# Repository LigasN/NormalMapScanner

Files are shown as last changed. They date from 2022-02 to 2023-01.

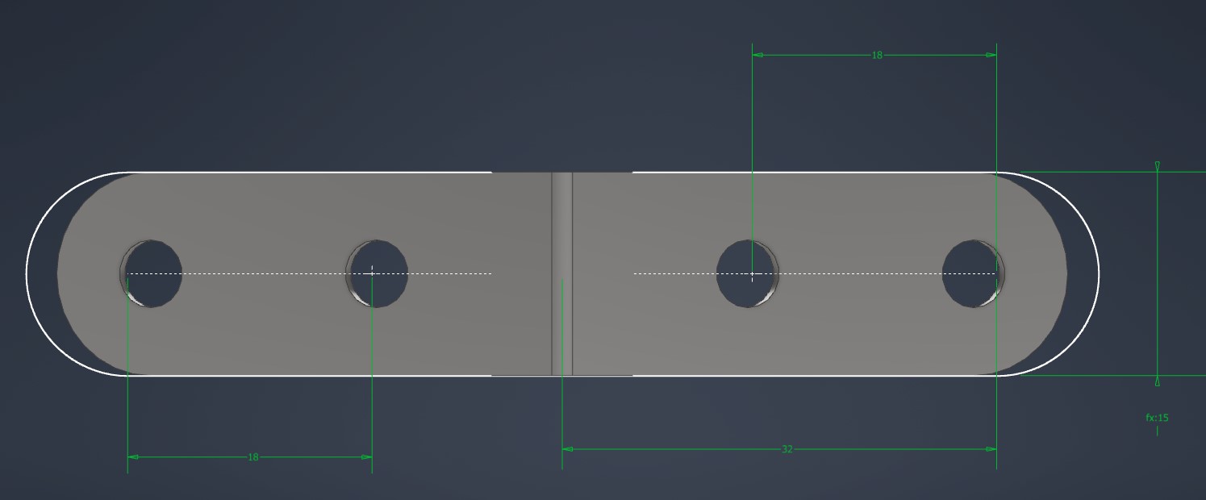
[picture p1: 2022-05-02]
3D_modeling/construction/images/parts/angle_iron_annotations.jpg

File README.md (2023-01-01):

NormalMapScanner https://www.youtube.com/watch?v=KlRckV2yOt0 (https://www.youtube.com/watch?v=KlRckV2yOt0)
# NormalMapScanner
Experimental stand for generating normal maps for quasi-flat objects.

## Description
A fully automatic system that generates normal maps for nearly flat objects. The process of generation consists in taking pictures with spotlighting from different sides and computation of normals. The repository consists of all projects (hardware and software) that combined result in a working stand.

## Discussions
I would like to kindly invite you to check the [discussions page](https://github.com/LigasN/NormalMapScanner/discussions).

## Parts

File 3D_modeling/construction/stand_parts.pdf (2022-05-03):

Name | Image | Amount | Placement Description | Dimensions | Images with annotations
bar_185mm | 8 | leg | Bar placed in the
| | | stand's leg to make possible
| | | changing leg heigth and by that
| | | light source heigth as well, as it is placed on the top part of the leg.
diameter [mm] | 8
heigth [mm] | 185
bar_285mm | 8 | arm | Bar placed in the stand's arm to make possible
| | | changing arm length and by that camera position (heigth) as well.
diameter [mm] | 8
heigth [mm] | 285
bar_connector | 16 | connector | Bar used in the connector's assembly to make possible its width

change. On one
side bar has holes
for screws to attach it to the leg. Lenght was

calculated on the premise that minimum distance between light and

stand center will be 400mm. Then

calculations were:
(
light_to_center_di
stance * sin(alfa) )
/ cos(alfa / 2), where alfa was

the difference between angles of direction of the

consecutives light
sources. Two legs and the stand

center make
triangle with this angle from the

center side.

diameter [mm] | 8
length [mm] | 271

first hole distance
to the edge [mm]

7,5

second hole distance to the edge [mm]

25,5

cut length [mm] | 35
pipe_200mm | 8 | leg | Leg's pipe. One of the holes is to hold bar on certain position and

second to connect with barrel hinge.

length [mm] | 200

inner diameter
[mm]

10

thickness [mm] | 1

upper hole distance to the edge [mm]

8

lower hole distance
to the edge [mm]

10

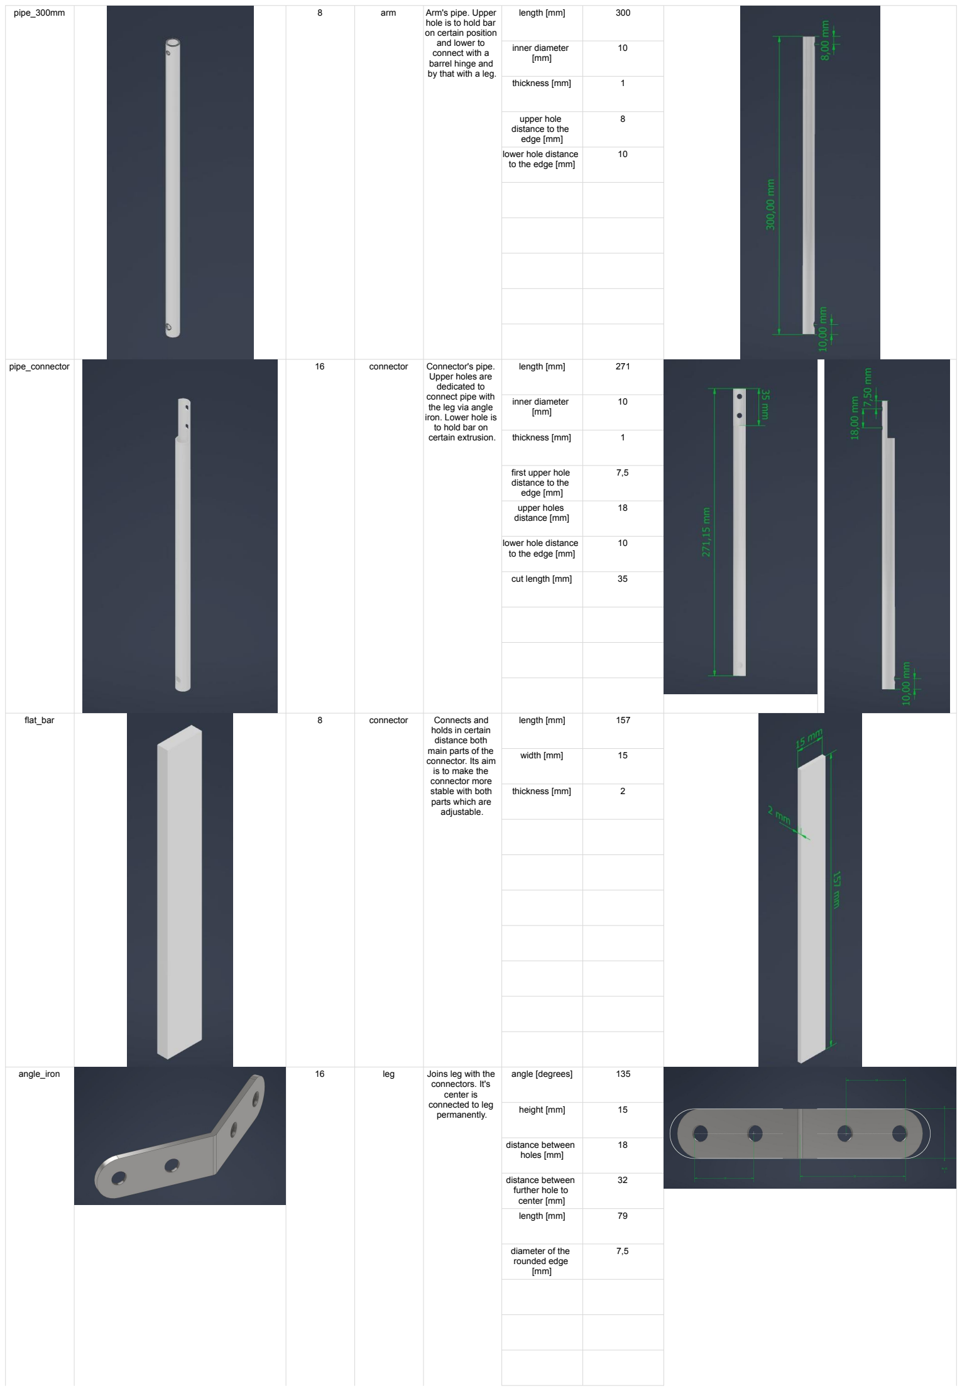
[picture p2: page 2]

pipe_300mm | 8 | arm | Arm's pipe. Upper hole is to hold bar on certain position and lower to

connect with a barrel hinge and by that with a leg.

length [mm] | 300

inner diameter
[mm]

10

thickness [mm] | 1

upper hole distance to the edge [mm]

8

lower hole distance
to the edge [mm]

10

pipe_connector | 16 | connector | Connector's pipe. Upper holes are dedicated to

connect pipe with
the leg via angle
iron. Lower hole is
to hold bar on
certain extrusion.
length [mm] | 271

inner diameter
[mm]

10

thickness [mm] | 1

first upper hole distance to the edge [mm]
7,5

upper holes distance [mm]

18

lower hole distance
to the edge [mm]

10

cut length [mm] | 35
flat_bar | 8 | connector | Connects and holds in certain distance both main parts of the

connector. Its aim
is to make the
connector more
stable with both parts which are adjustable.
length [mm] | 157
width [mm] | 15
thickness [mm] | 2
angle_iron | 16 | leg | Joins leg with the connectors. It's center is connected to leg permanently.
angle [degrees] | 135
height [mm] | 15

distance between holes [mm]

18

distance between
further hole to
center [mm]

32

length [mm] | 79

diameter of the
rounded edge
[mm]

7,5

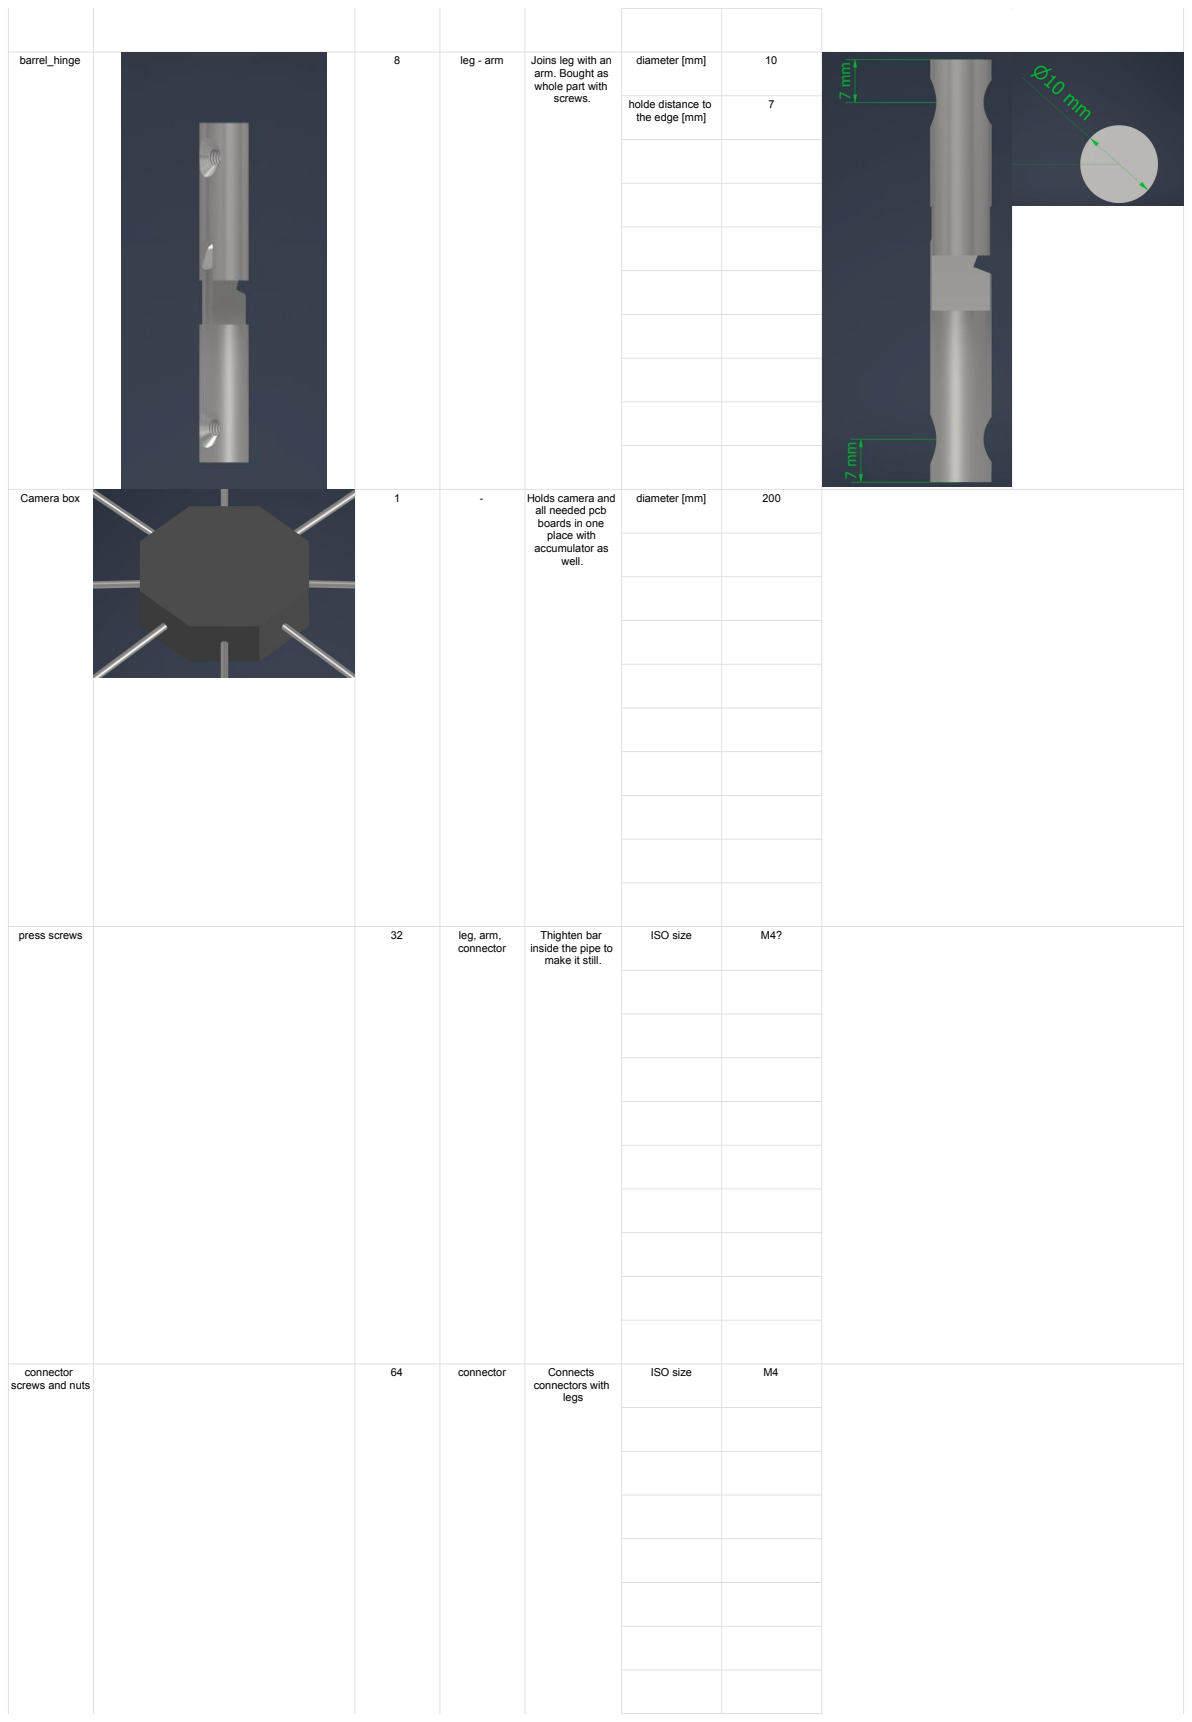
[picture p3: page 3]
barrel_hinge; leg - arm; Joins leg with an arm. Bought as whole part with; screws.; diameter [mm]; Camera box; Holds camera and all needed pcb boards in one place with accumulator as well.; press screws; leg, arm,; connector; ISO size; Connects; connectors with legs

holde distance to
the edge [mm]

Thighten bar
inside the pipe to make it still.

connector
screws and nuts

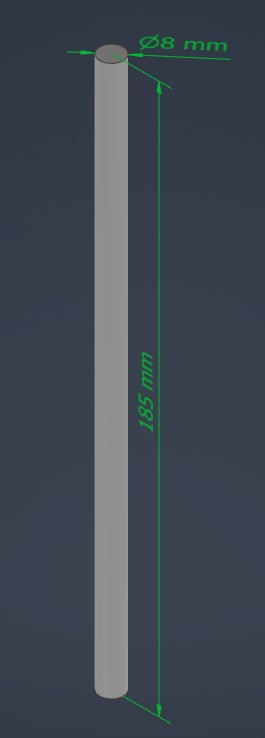
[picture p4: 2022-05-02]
3D_modeling/construction/images/parts/bar_185mm_annotations.jpg

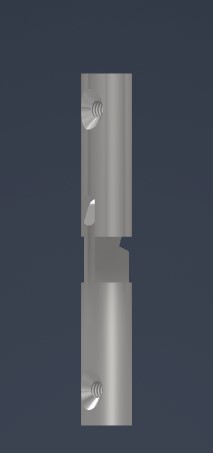
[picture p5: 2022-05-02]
3D_modeling/construction/images/parts/barrel_hinge.jpg

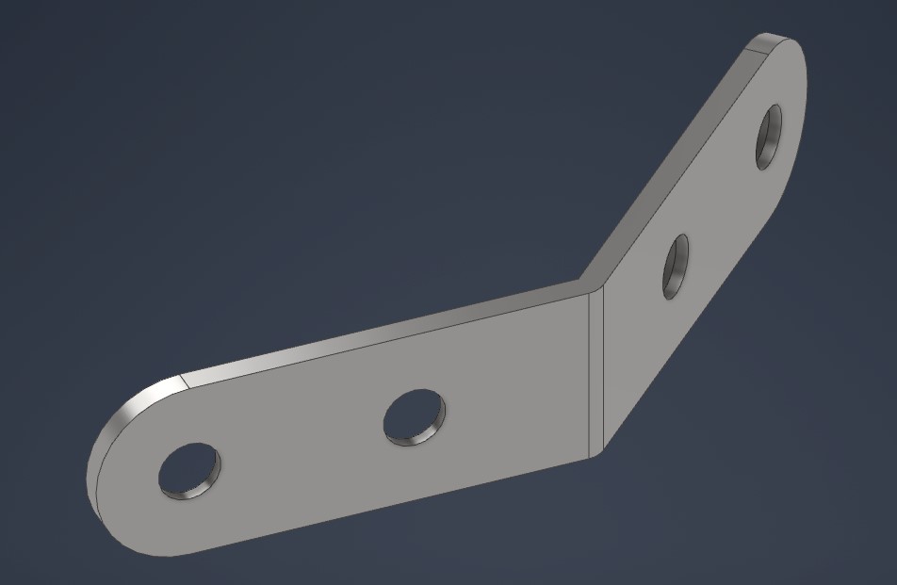
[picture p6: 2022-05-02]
3D_modeling/construction/images/parts/angle_iron.jpg

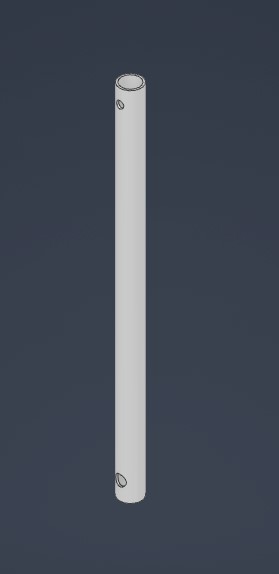
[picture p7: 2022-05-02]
3D_modeling/construction/images/parts/pipe_200mm.jpg

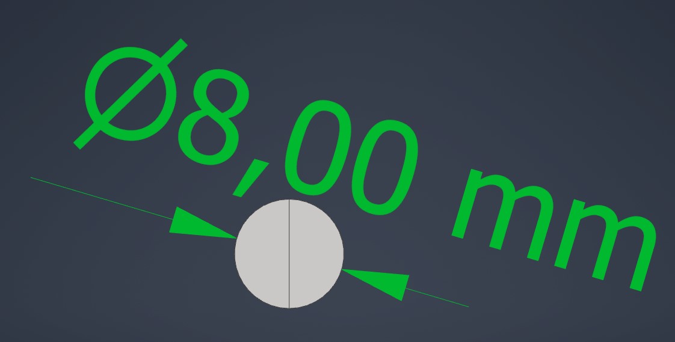
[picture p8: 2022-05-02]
3D_modeling/construction/images/parts/bar_connector_top_annotations.jpg

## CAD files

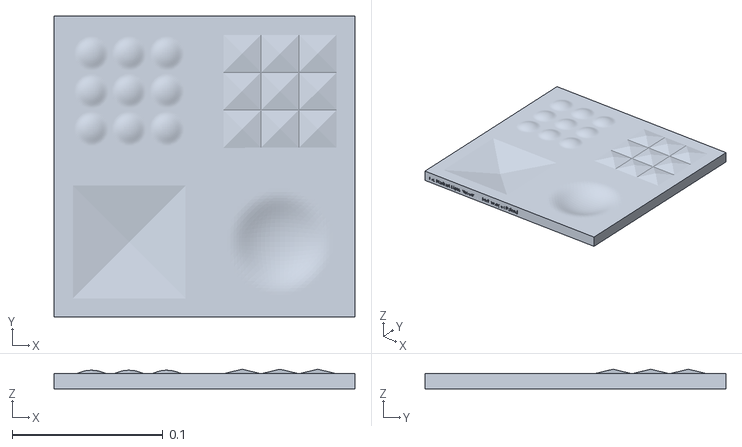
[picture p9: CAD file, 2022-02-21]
3D_modeling/3D_print_models/dice.stl
0.2 x 0.2 x 0.013

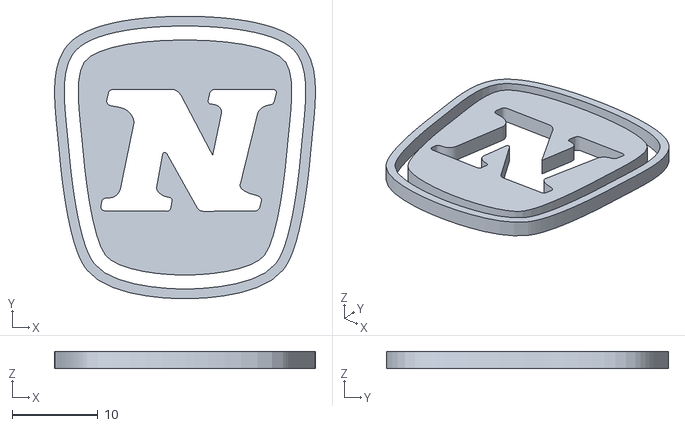
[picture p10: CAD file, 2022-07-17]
3D_modeling/construction/parts/board_box/board_box_cover_assets/n-logo.stl
30.4 x 32.9 x 2.00

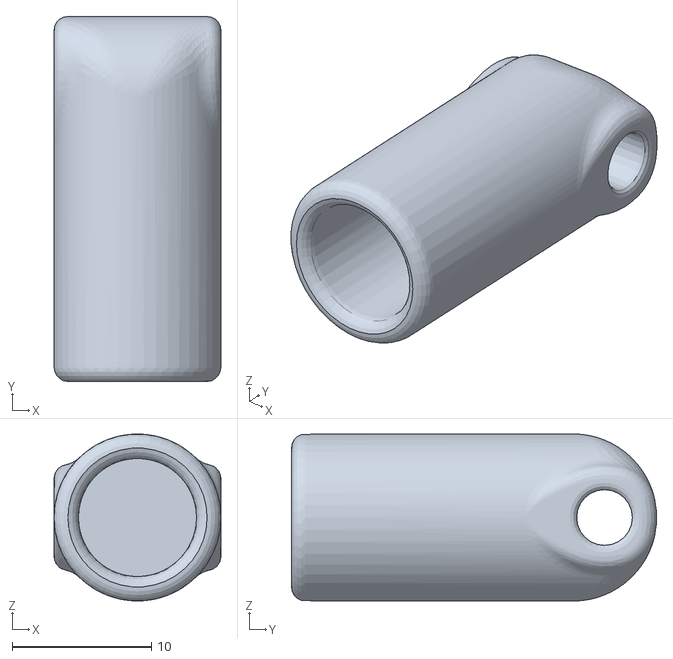
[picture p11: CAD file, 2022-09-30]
3D_modeling/construction/stl/bar_holder.stl
12.0 x 26.2 x 12.0

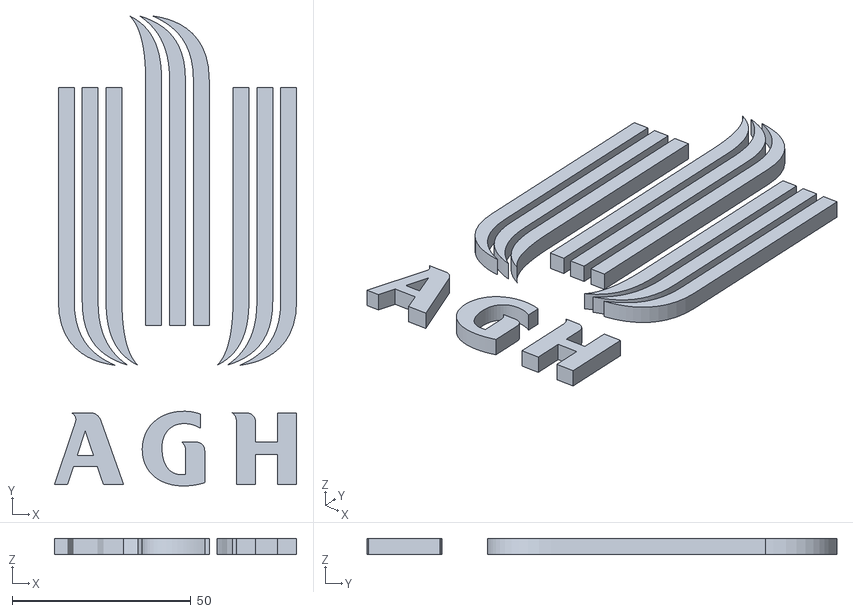
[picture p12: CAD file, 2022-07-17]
3D_modeling/construction/parts/board_box/board_box_cover_assets/agh_logo.stl
67.8 x 131.6 x 4.59

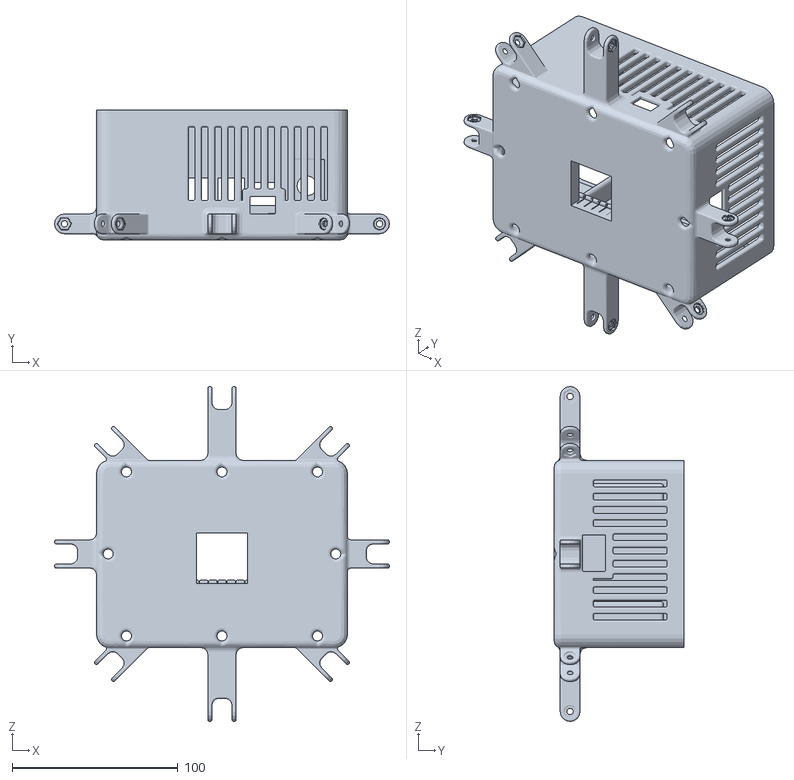
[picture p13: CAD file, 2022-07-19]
3D_modeling/construction/stl/board_box_bottom.stl
202.0 x 78.2 x 202.0

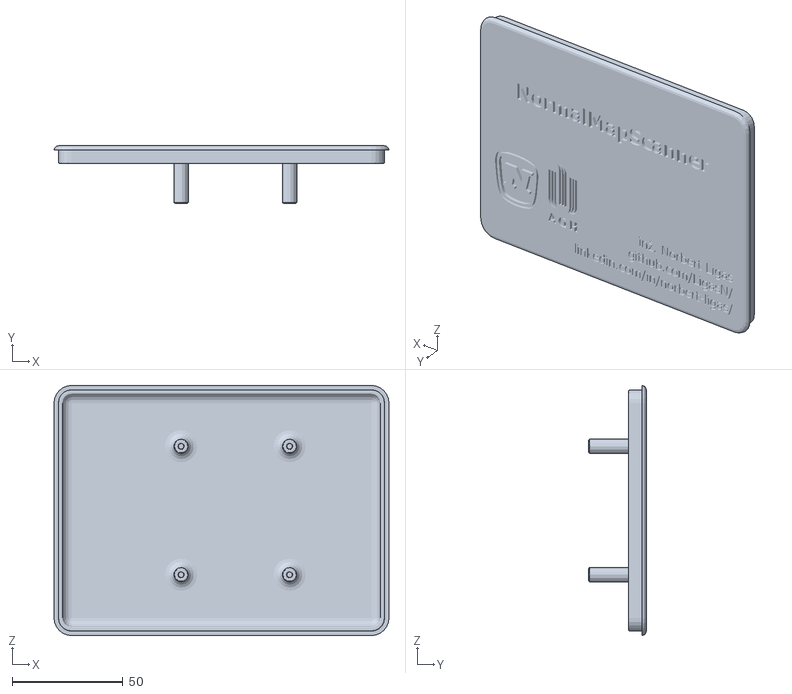
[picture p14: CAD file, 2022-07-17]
3D_modeling/construction/stl/board_box_cover.stl
151.3 x 26.0 x 113.0

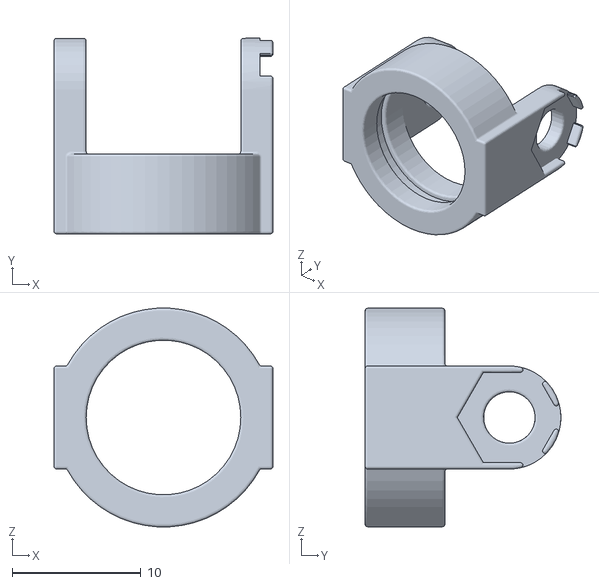
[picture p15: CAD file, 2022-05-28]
3D_modeling/construction/stl/light_holder_part1.stl
17.0 x 15.2 x 17.0

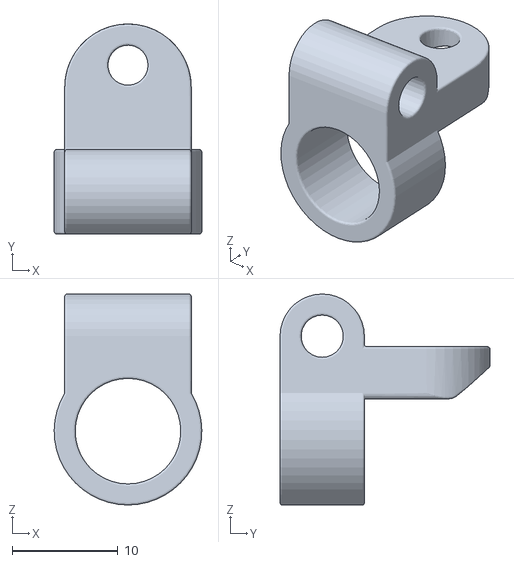
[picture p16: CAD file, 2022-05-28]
3D_modeling/construction/stl/light_holder_part2.stl
14.0 x 19.9 x 20.0

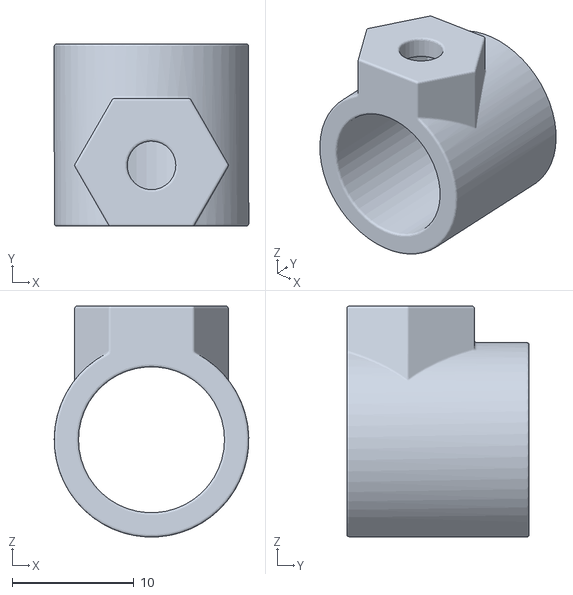
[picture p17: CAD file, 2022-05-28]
3D_modeling/construction/stl/nut_holder.stl
16.0 x 15.0 x 19.0

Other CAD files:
3D_modeling/3D_print_models/stand_model_with_signature.blend
3D_modeling/construction/parts/adjustable_arm.iam
3D_modeling/construction/parts/adjustable_connector.iam
3D_modeling/construction/parts/adjustable_double_connector.iam
3D_modeling/construction/parts/adjustable_leg.iam
3D_modeling/construction/parts/angle_iron.ipt
3D_modeling/construction/parts/bar_185mm.ipt
3D_modeling/construction/parts/bar_285mm.ipt
3D_modeling/construction/parts/bar_connector.ipt
3D_modeling/construction/parts/barrel_hinge-female.ipt
3D_modeling/construction/parts/barrel_hinge-male.ipt
3D_modeling/construction/parts/barrel_hinge.iam
3D_modeling/construction/parts/board_box.iam
3D_modeling/construction/parts/board_box/RaspberryCameraV2Case.ipt
3D_modeling/construction/parts/board_box/RaspberryCameraV2InCase.iam
3D_modeling/construction/parts/board_box/RaspberryPiCameraV2.ipt
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

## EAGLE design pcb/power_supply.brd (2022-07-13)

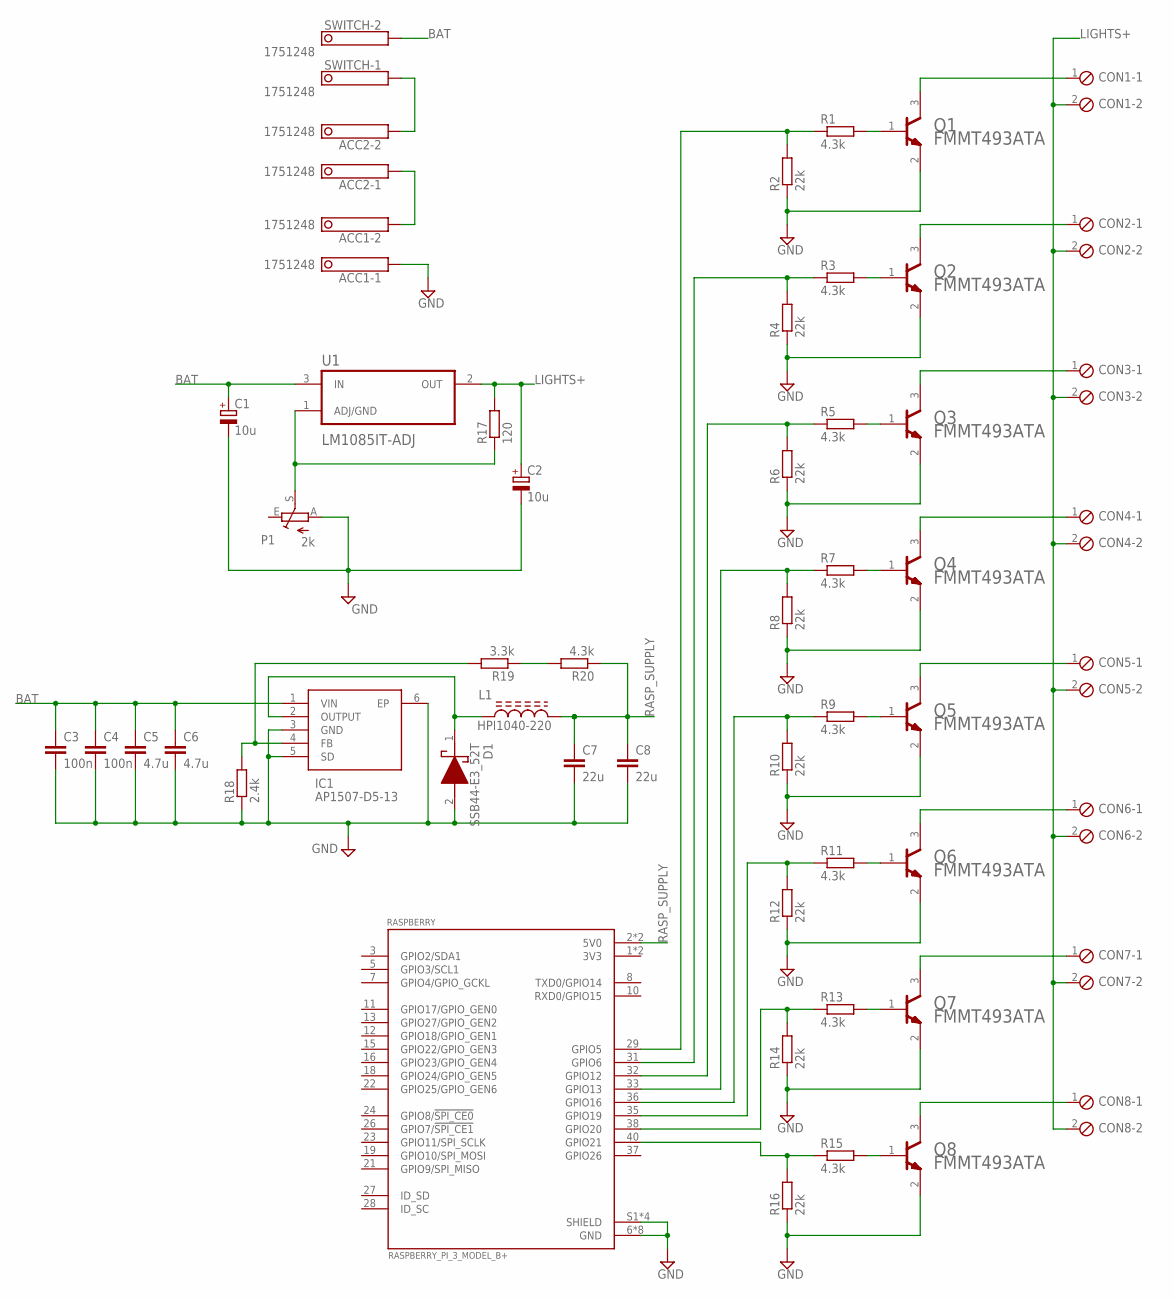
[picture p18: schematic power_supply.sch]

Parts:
ACC1, ACC2: 1751248
C1, C2: 10u; B/3528-21R
C3, C4: 100n; C0603
C5, C6: 4.7u; C1206
C7, C8: 22u; C1206
CON1, CON2, CON3, CON4, CON5, CON6, CON7, CON8: +; 2POL254
D1: SSB44-E3_52T; DIOM5436X244N
IC1: AP1507-D5-13; AP1507D513
L1: HPI1040-220; INDM102100X510N
P1: 2k; CA6V
Q1, Q2, Q3, Q4, Q5, Q6, Q7, Q8: DIODES_FMMT493ATADIODES_FMMT493ATA_0_0; DIODES_FMMT493ATA_0
R1, R3, R5, R7, R9, R11, R13, R15, R20: 4.3k; R0805
R2, R4, R6, R8, R10, R12, R14, R16: 22k; R0805
R17: 120; R0805
R18: 2.4k; R0805
R19: 3.3k; R0805
RASPBERRY: RASPBERRY_PI_3_MODEL_B+; MODULE_RASPBERRY_PI_3_MODEL_B+
SWITCH: 1751248
U1: LM1085IT-ADJ; TO254P1054X470X1955-3

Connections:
3V3: RASPBERRY.1 (3V3), RASPBERRY.17 (3V3)
BAT: C1.+, C3.1, C4.1, C5.1, C6.1, IC1.1 (VIN), SWITCH.2, U1.3 (IN)
GND: ACC1.1, C1.-, C2.-, C3.2, C4.2, C5.2, C6.2, C7.2, C8.2, D1.2 (A), IC1.3 (GND), IC1.5 (SD), IC1.6 (EP), P1.A, Q1.2 (E), Q2.2 (E), Q3.2 (E), Q4.2 (E), Q5.2 (E), Q6.2 (E), Q7.2 (E), Q8.2 (E), R2.1, R4.1, R6.1, R8.1, R10.1, R12.1, R14.1, R16.1, R18.1, RASPBERRY.6 (GND), RASPBERRY.9 (GND), RASPBERRY.14 (GND), RASPBERRY.20 (GND), RASPBERRY.25 (GND), RASPBERRY.30 (GND), RASPBERRY.34 (GND), RASPBERRY.39 (GND), RASPBERRY.S1 (SHIELD), RASPBERRY.S2 (SHIELD), RASPBERRY.S3 (SHIELD), RASPBERRY.S4 (SHIELD)
LIGHTS+: C2.+, CON1.2, CON2.2, CON3.2, CON4.2, CON5.2, CON6.2, CON7.2, CON8.2, R17.2, U1.2 (OUT)
unnamed: CON1.1, Q1.3 (C)
unnamed: R19.1, R20.2
unnamed: ACC1.2, ACC2.1
unnamed: IC1.4 (FB), R18.2, R19.2
unnamed: Q2.1 (B), R3.2
unnamed: CON2.1, Q2.3 (C)
unnamed: ACC2.2, SWITCH.1
unnamed: Q3.1 (B), R5.2
unnamed: CON3.1, Q3.3 (C)
unnamed: Q4.1 (B), R7.2
unnamed: CON4.1, Q4.3 (C)
unnamed: Q5.1 (B), R9.2
unnamed: CON5.1, Q5.3 (C)
unnamed: R1.1, R2.2, RASPBERRY.29 (GPIO5)
unnamed: R3.1, R4.2, RASPBERRY.31 (GPIO6)
unnamed: R5.1, R6.2, RASPBERRY.32 (GPIO12)
unnamed: Q1.1 (B), R1.2
unnamed: R7.1, R8.2, RASPBERRY.33 (GPIO13)
unnamed: R9.1, R10.2, RASPBERRY.36 (GPIO16)
unnamed: R11.1, R12.2, RASPBERRY.35 (GPIO19)
unnamed: R13.1, R14.2, RASPBERRY.38 (GPIO20)
unnamed: R15.1, R16.2, RASPBERRY.40 (GPIO21)
unnamed: P1.S, R17.1, U1.1 (ADJ/GND)
unnamed: D1.1 (K), IC1.2 (OUTPUT), L1.1
unnamed: Q6.1 (B), R11.2
unnamed: CON6.1, Q6.3 (C)
unnamed: Q7.1 (B), R13.2
unnamed: CON7.1, Q7.3 (C)
unnamed: Q8.1 (B), R15.2
unnamed: CON8.1, Q8.3 (C)
RASP_SUPPLY: C7.1, C8.1, L1.2, R20.1, RASPBERRY.2 (5V0), RASPBERRY.4 (5V0)

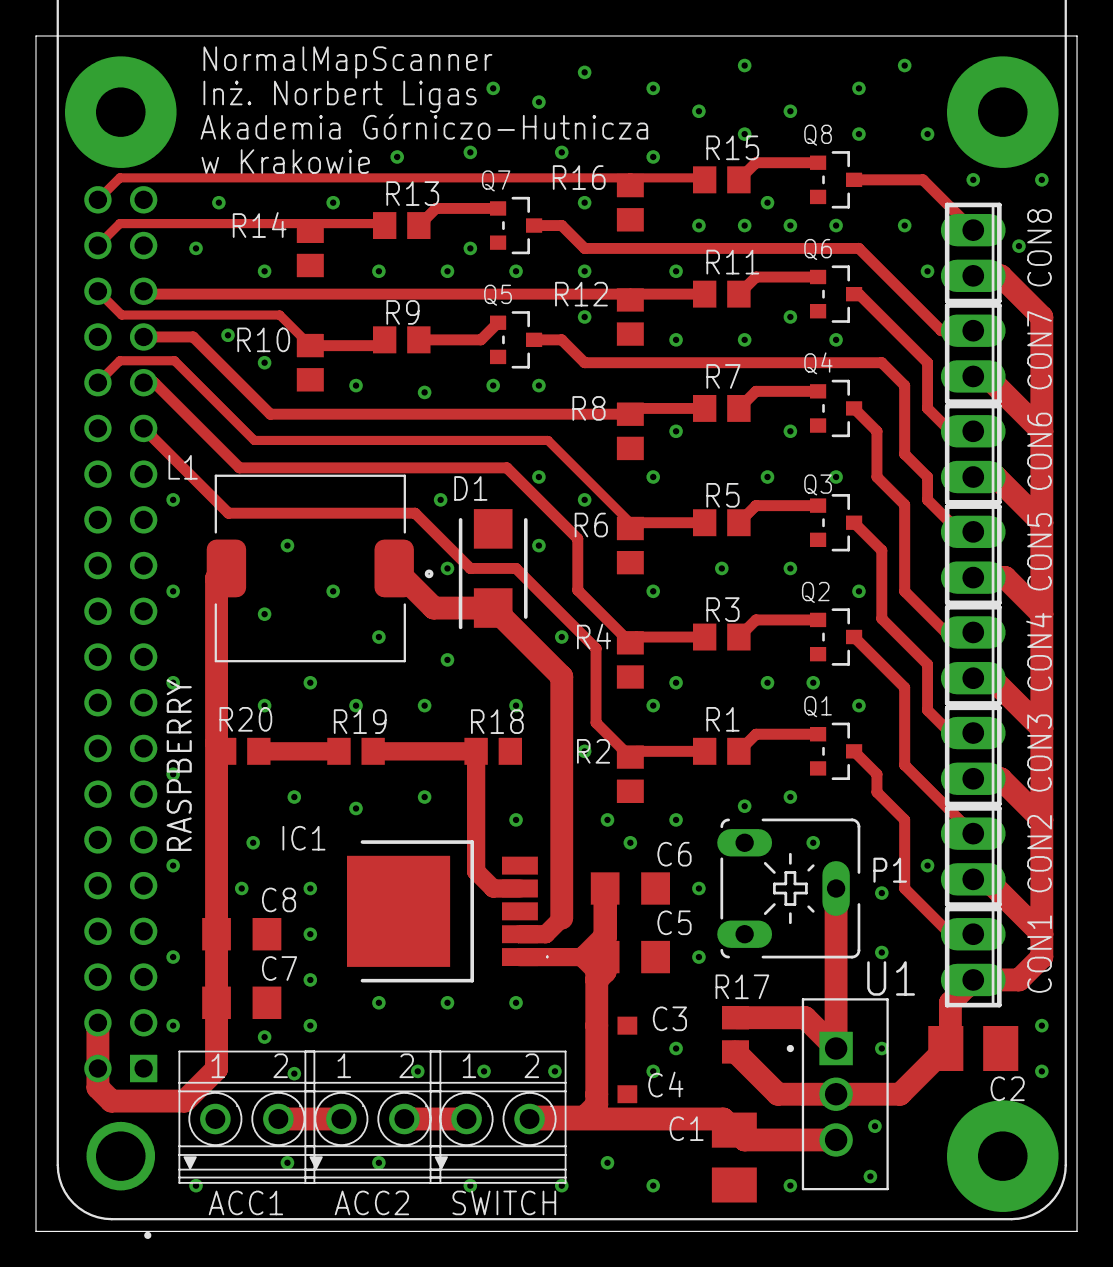
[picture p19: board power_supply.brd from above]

Board: 2 copper layers, 57.8 x 66.4 mm, 53 parts (0 on the bottom side), 35 nets.

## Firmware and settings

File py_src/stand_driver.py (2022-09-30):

import RPi.GPIO as GPIO
from picamera import PiCamera
import time
import os


# Dictionary with GPIO ID for specific light angle

class Stand:
    LightsGPIO = {
        0: 5,
        45: 6,
        90: 12,
        135: 13,
        180: 16,
        225: 19,
        270: 20,
        315: 21
    }
    shot_delay = 1

    def __init__(self, input_filename_prefix, 
            environment_filename, resolution):
        self.camera = PiCamera()
        self.camera.resolution = resolution
        self.camera.rotation = 180

        GPIO.setmode(GPIO.BCM)
        #GPIO.setwarnings(False)
        for GPIOID in Stand.LightsGPIO.values():
            GPIO.setup(GPIOID, GPIO.OUT, initial=0)

        self.input_filename_prefix = input_filename_prefix
        self.environment_filename = environment_filename
        self.resolution = resolution

        self.__IntroTest()

    def __del__(self):
        self.camera.close()
        GPIO.cleanup()

    def __TurnAllLightsOn(self):
        for lightGPIO in self.LightsGPIO.values():
            GPIO.output(lightGPIO, GPIO.HIGH)

    def __TurnAllLightsOff(self):
        for lightGPIO in self.LightsGPIO.values():
            GPIO.output(lightGPIO, GPIO.LOW)

    def __IntroTest(self):
        intro_lights_change_delay = 0.05
        self.__TurnAllLightsOff()
        for _ in range(0,2):
            for lightGPIO in self.LightsGPIO.values():
                GPIO.output(lightGPIO, GPIO.HIGH)
                time.sleep(intro_lights_change_delay)
                GPIO.output(lightGPIO, GPIO.LOW)

    def __makeSingleShot(self, angle, output_filepath):
        GPIO.output(Stand.LightsGPIO[angle], GPIO.HIGH)
        time.sleep(self.shot_delay)
        self.camera.capture(output_filepath)
        time.sleep(self.shot_delay)
        GPIO.output(Stand.LightsGPIO[angle], GPIO.LOW)

    def __makeEnviromentLightShot(self, path):
        self.camera.capture(path + "/" + 
            self.input_filename_prefix + self.environment_filename + ".bmp")


    def setResolution(self, resolution):
        self.camera.resolution = resolution

    def getResolution(self):
        return self.camera.resolution


    def gatherAllAssets(self, save_path, preview_callback = None):
        self.__makeEnviromentLightShot(save_path)
        output_filepath = None 
        for angle in self.LightsGPIO.keys():
            output_filepath = os.path.join(os.path.abspath(save_path),
                self.input_filename_prefix + str(angle) + ".bmp")
            self.__makeSingleShot(angle, output_filepath)
        if preview_callback:
            preview_callback(output_filepath)


    def checkCameraToPath(self, path):
        self.__TurnAllLightsOn()
        time.sleep(self.shot_delay)
        self.camera.capture(path)
        time.sleep(self.shot_delay)
        self.__TurnAllLightsOff()

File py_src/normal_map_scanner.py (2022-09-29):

import os
import sys
from threading import Thread
import time
from PIL import Image
import numpy as np
from datetime import datetime
import glob

from kivy.app import App
from kivy.core.window import Window
from kivy.uix.widget import Widget
from kivy.uix.gridlayout import GridLayout
from kivy.uix.floatlayout import FloatLayout
from kivy.uix.label import Label
from kivy.uix.image import Image as uiImage
from kivy.uix.button import Button
from kivy.uix.textinput import TextInput
from kivy.uix.screenmanager import ScreenManager, Screen, NoTransition
from kivy.properties import ObjectProperty, StringProperty
from kivy.uix.popup import Popup
from kivy.utils import platform
from kivy.logger import Logger
from kivy.clock import Clock
from kivy.uix.settings import SettingsWithNoMenu
import logging

from normal_map.normal_map import NormalMap

try:
    from stand_driver import Stand
except:
    print("Running in no raspbery mode!")


# Properties
sourcefiles = dict()
input_filename_prefix = "input_"
assets_parent_directory = "input_assets/"
tmp_dir = "tmp/"
workspace_path = "./"
environment_filename = "all_off"
output_file = "normalmap.bmp"
max_resolution =  np.array([3280, 2464]) #px
default_resolution = np.array([3280, 2464]) #px
object_size = (50, 50) #cm
lamp_0_position = (55, 0, 35) #cm
verbosity = 1 # Only status

def load_image(filename):
    try:
        return Image.open(filename)
    except FileNotFoundError:
        print('File not found: ' + filename)


def calculateNormalMap(session_abs_path, set_progress_bar_value_function, 
        is_asked_to_exit, is_done_callback):
    assets_path = os.path.join(session_abs_path, assets_parent_directory)
    for angle in NormalMap.angles:
        filename = input_filename_prefix + str(angle) + '.bmp'
        filepath = os.path.join(assets_path, filename)
        sourcefiles[angle] = load_image(filepath)

    environment_file_name = input_filename_prefix + environment_filename + '.bmp'
    environment_path = os.path.join(os.path.abspath(assets_path), environment_file_name)
    environment_light = load_image(environment_path)

    normalmap = NormalMap(source_files=sourcefiles,
                          object_size=object_size,
                          lamp_0_position=lamp_0_position,
                          environment_light=environment_light)

    normalmap.calculateNormalMap(verbosity=verbosity, log=True, 
        progressbar=True, set_progress_bar_value_function=set_progress_bar_value_function,
        is_asked_to_exit=is_asked_to_exit)

    if normalmap.normalmap:
        if verbosity >= 1:
            #normalmap.normalmap.show()
            print('Saving')

        normalmap.normalmap.save(os.path.join(session_abs_path, output_file))
    is_done_callback()


# Stand object
try:
    g_stand = Stand(input_filename_prefix=input_filename_prefix,
        environment_filename=environment_filename,
        resolution = default_resolution)
except:
    pass

# -----------------------------------------------------------------------------
#                                    GUI
# -----------------------------------------------------------------------------

#Logger.setLevel(logging.TRACE)
Window.fullscreen = True
#Window.size = (960, 540)


class ChooseWorkspaceDialog(FloatLayout):
    change_workspace = ObjectProperty(None)
    cancel = ObjectProperty(None)

class MenuScreen(Screen):

    def dismiss_popup(self):
        self._popup.dismiss()

    def show_change_workspace_menu(self):
        content = ChooseWorkspaceDialog(change_workspace=self.change_workspace, cancel=self.dismiss_popup)
        self._popup = Popup(title="Change workspace", content=content,
                            size_hint=(0.9, 0.9))
        self._popup.open()

    def change_workspace(self, path):
        global workspace_path
        workspace = os.path.join(path)
        if os.path.isdir(workspace):
            workspace_path = workspace
            self.ids.workspace_id.refresh_workspace_path_label()
            self.dismiss_popup()


class GatherScreen(Screen):
    def on_pre_enter(self):
        self.ids.workspace_id.refresh_workspace_path_label()
        self.__reload_check_image()
        resolution = g_stand.getResolution()
        self.ids.resolutionWidthTextInput.text = str(resolution[0])
        self.ids.resolutionHeightTextInput.text = str(resolution[1])

    def check_camera(self):
        tmp_path = os.path.join(os.path.abspath(workspace_path), tmp_dir)
        if not os.path.exists(tmp_path):
            os.makedirs(tmp_path, exist_ok=True)
        check_filepath =  os.path.join(tmp_path, "tmp.png")
        g_stand.checkCameraToPath(check_filepath)
        self.__reload_check_image(check_filepath)

    def __reload_check_image(self, image_filepath = "./tmp/tmp.png"):
        if os.path.exists(image_filepath):
            self.ids.check_image.source = os.path.join(os.path.abspath(image_filepath))
        else:
            self.ids.check_image.source = os.path.join("./assets/preview.jpg")
        self.ids.check_image.reload()

    def capture_all_assets(self):
        session_dir = datetime.now().strftime('%Y-%m-%d_%H.%M.%S')
        save_path = os.path.join(os.path.abspath(workspace_path), session_dir, assets_parent_directory)
        if not os.path.exists(save_path):
            os.makedirs(save_path, exist_ok=True)
        g_stand.gatherAllAssets(save_path = save_path,
            preview_callback = self.__reload_check_image)

    def set_resolution(self):
        try:
            resolution = np.array([int(self.ids.resolutionWidthTextInput.text), int(self.ids.resolutionHeightTextInput.text)])
            Logger.info('Settings: try to set resolution: ' + str(resolution))
            g_stand.setResolution(resolution)
        except:
            Logger.error('Settings: failed to set resolution to: [' + self.ids.resolutionWidthTextInput.text + ', ' + self.ids.resolutionHeightTextInput.text + ']')
            resolution = g_stand.getResolution()
            self.ids.resolutionWidthTextInput.text = str(resolution[0])
            self.ids.resolutionHeightTextInput.text = str(resolution[1])
        else:
            Logger.info('Settings: resolution set to: ' + str(resolution))


class CalculateScreen(Screen):
    session_path = os.path.abspath(workspace_path)
    gather_input_message_value = ["Please gather input images first"]
    assets_paths_list = []
    asked_to_exit = False
    thread = None
    spinner_last_value = None

    def __init__(self,**kwargs):
        super(CalculateScreen, self).__init__(**kwargs)

    def __del__(self):
        self.asked_to_exit = True
        if self.thread:
            self.thread.join()

    def exit(self):
        self.asked_to_exit = True
        if self.thread:
            self.thread.join()
        self.manager.current = 'menu_screen'

    def is_asked_to_exit(self):
        if (True == self.asked_to_exit):
            self.asked_to_exit = False
            return True
        return False

    def is_done(self):
        self.__refresh_normalmap()

    def __refresh_normalmap(self):
        self.ids.normal_map_image.source = os.path.join(os.path.abspath(self.session_path), output_file)

        if not os.path.exists(self.ids.normal_map_image.source):
            self.ids.normal_map_image.source = os.path.join("./assets/preview.jpg")
        
        Logger.info("Image: source set to: " + self.ids.normal_map_image.source)
        self.ids.normal_map_image.reload()
        Logger.info("Image: reloaded")

    def on_pre_enter(self):
        self.asked_to_exit = False
        self.ids.workspace_id.refresh_workspace_path_label()
        self.reload_current_assets_path()
        self.set_progress_bar_value(0)
        self.__refresh_normalmap()

    def reload_current_assets_path(self):
        self.assets_paths_list.clear()
        abs_workspace_path = os.path.abspath(workspace_path)
        if os.path.isdir(abs_workspace_path):
            if self.spinner_last_value != None:
                self.session_path = os.path.join(abs_workspace_path, self.spinner_last_value)
            for dir_name in os.listdir(abs_workspace_path):
                possible_assets_path = os.path.join(abs_workspace_path, dir_name, assets_parent_directory)
                possible_asset_file_path = os.path.join(possible_assets_path, "*.bmp")
                if os.path.isdir(possible_assets_path) and glob.glob(possible_asset_file_path):
                    self.assets_paths_list.append(dir_name)

        if self.assets_paths_list:
            self.ids.spinner_id.values = self.assets_paths_list
        else:
            self.ids.spinner_id.values = self.gather_input_message_value

    def spinner_clicked(self, value):
        self.spinner_last_value = value
        self.session_path = os.path.join(os.path.abspath(workspace_path), value)
        self.__refresh_normalmap()

    def set_progress_bar_value(self, percentage_value):
        self.ids.progress_bar.value = percentage_value
        self.ids.progress_label.text = "{:.2f}".format(percentage_value) + '%'
        
    def calculate_normal_map(self):
        assets_path = os.path.join(self.session_path, assets_parent_directory, "*.bmp")
        if os.path.isdir(self.session_path) and glob.glob(assets_path):
            self.set_progress_bar_value(0)
            self.thread = Thread(target = calculateNormalMap, args = (self.session_path, self.set_progress_bar_value, self.is_asked_to_exit, self.is_done))
            self.thread.start()


class WorkspaceWidget(FloatLayout):
    workspace_path_property = StringProperty(os.path.abspath(workspace_path))
    def refresh_workspace_path_label(self):
        self.ids.workspace_path_label.text = "Workspace path: " + os.path.abspath(workspace_path)


class NormalMapScannerApp(App):

    def build(self):
        # Create the screen manager
        sm = ScreenManager()
        sm.transition = NoTransition()
        sm.add_widget(MenuScreen(name='menu_screen'))
        sm.add_widget(GatherScreen(name='gather_screen'))
        sm.add_widget(CalculateScreen(name='calculate_screen'))

        return sm


if __name__ == '__main__':
    NormalMapScannerApp().run()
    sys.exit()

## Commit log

2021-11-21 Trying to get experimental 3D model in blender
    [dice.blend]
2021-11-21 blob as figure 2
    [dice.blend]
2021-11-21 cuboid sculpture done
    [dice.blend]
2022-01-06 camera properties as the real one
    [dice.blend]
2022-01-06 some repo cleaning
    [dice.blend, stand_model.blend]
2022-01-07 light source model
    [stand_model.blend]
2022-01-07 Light rotation
    [stand_model.blend]
2022-01-08 NormalMap material
    [stand_model.blend]
2022-01-08 all light sources, and input images v.1
    [stand_model.blend]
2022-01-18 Bake the normal map
    [stand_model.blend]
2022-01-20 linear color space image generation
    [stand_model.blend]
2022-01-23 normals calculation - not working v.1
    [normal_map_scanner.py]
2022-02-04 Error in conversion to image - pillow assumes uint8 array
    [normal_map_scanner.py]
2022-02-05 NormalMap algorithm output in blender
    [stand_model.blend]
2022-02-09 simple test images
    [stand_test_model_4x4.blend]
2022-02-16 Prints commented out; Equations comment improved
2022-02-16 New normal map check
    [stand_model.blend]
2022-02-21 3D printing models with signature
    [cuboid.stl, dice.stl, stand_model_with_signature.blend]
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2022-02-24 better rounded piece in model
    [dice.blend]
2022-02-24 improved model's mesh
    [cuboid.stl]
2022-03-05 GUI with informations about camera status and errors. No correct text placed yet
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2022-03-21 Huge commit (sorry for that) - real model scanning by hand, camera initialisation (synchronisation fixed and now overrun error)
    [normal_map_scanner.py]
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2022-04-22 stand construction - barrel hinge female
    [barrel_hinge-female.ipt]
2022-04-23 barrel_hinge-male and update for female part
    [barrel_hinge-female.ipt, barrel_hinge-male.ipt]
2022-04-23 parametrized bar
    [bar.ipt]
2022-04-23 power supply circuit - Linear Voltage Regulator
    [power_supply.sch]
2022-04-24 pipe and corrected bar length
    [bar.ipt, pipe.ipt]
2022-04-24 barrel hinge
    [barrel_hinge-male.ipt, barrel_hinge.iam, stand.iam]
2022-04-26 adjustable leg with hinge attached
    [adjustable_leg.iam, bar.ipt, bar_185mm.ipt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]
2022-04-27 leg with bolts
    [adjustable_leg.iam]
2022-04-27 angle iron
    [adjustable_leg.iam, angle_iron.ipt]
2022-04-27 all parts seems ready
    [adjustable_arm.iam, adjustable_connector.iam, adjustable_double_connector.iam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]
2022-04-30 fix of flat bar length, connection of some parts in stand
    [adjustable_connector.iam, adjustable_double_connector.iam, adjustable_leg.iam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]
2022-05-01 legs connected
    [adjustable_double_connector.iam, adjustable_leg.iam, flat_bar.ipt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]
2022-05-01 legs grounded
    [adjustable_double_connector.iam, adjustable_leg.iam, flat_bar.ipt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]
2022-05-01 stand connected, box for pcb boards
    [adjustable_arm.iam, adjustable_connector.iam, adjustable_double_connector.iam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]
2022-05-02 pcb - connectors, raspberry
    [power_supply.sch]
2022-05-02 stand construction - making part list v.1
    [adjustable_arm.iam, adjustable_double_connector.iam, adjustable_leg.iam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]
2022-05-03 stand construction - some refactoring in directory tree and summary in pdf
    [angle_iron.ipt]
2022-05-08 pcb - voltage regulators
    [power_supply.sch]
2022-05-10 pcb - lights switching, battery replacement to 2*6V
    [power_supply.sch]
2022-05-11 Some battery replacement and stuff
    [power_supply.sch]
2022-05-15 pcb - schematic done for now
    [power_supply.sch]
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2022-05-23 pcb - board
    [power_supply.brd, power_supply.sch]
2022-05-28 stand_construction - holders
    [light_holder.iam, light_holder_part1.ipt, light_holder_part1.stl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]
2022-05-28 pcb - not turning off leds fix
2022-06-02 raspberry - tools to test camera and GPIO
2022-06-19 pcb - new raspberry supply
    [power_supply.sch]
2022-06-25 pcb - schemat updated
    [power_supply.sch]
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2022-06-26 pcb - board partially updated
    [power_supply.brd, power_supply.sch]
2022-06-27 pcb - elements placed in the right places
    [power_supply.brd]
2022-06-27 pcb - routes placed
    [power_supply.brd]
2022-06-27 pcb - better supply route
    [power_supply.brd, power_supply.sch]
2022-06-27 pcb - 5V pins connected
    [power_supply.brd]
2022-06-27 pcb - ERC, DRC
    [power_supply.brd, power_supply.sch]
2022-06-27 pcb - GND top layer
    [power_supply.brd]
2022-06-27 pcb - vias placed
    [power_supply.brd]
2022-06-28 pcb - gerber files, pcb ordered
    [power_supply.brd]
2022-07-09 pcb - additional files
    [DRILEGEND.CFG]
2022-07-13 board_box - camera case is placed
    [1751248.ipt, 2POL254.ipt, AP1507D513.ipt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]
2022-07-14 board box - raspberry placed
    [RaspberryCameraV2InCase.iam, RaspberryPiCameraV2.ipt, board_box.iam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]
2022-07-15 board box - fixed camera box position
    [board_box.iam, board_box_bottom.ipt]
2022-07-15 board box - battery case placement
    [board_box.iam, board_box_bottom.ipt]
2022-07-15 board box - switch
    [On-OffTag.ipt, PanelNut.ipt, Part9.ipt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]
2022-07-15 board box - walls
    [board_box.iam, board_box_bottom.ipt]
2022-07-16 board box - holes
    [RaspberryCameraV2InCase.iam, Switch.iam, USB-A-stack-1x2 v23.iam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]
2022-07-16 board box - hdmi hole
    [board_box.iam, board_box_bottom.ipt]
2022-07-16 board box - leds hole
    [board_box.iam, board_box_bottom.ipt]
2022-07-16 board box - board box bottom is ready
    [board_box.iam, board_box_bottom.ipt]
2022-07-16 board box - cover
    [board_box.iam, board_box_cover.ipt]
2022-07-16 board box - text
    [board_box_cover.ipt]
2022-07-16 board box - bar holder
    [bar_holder.ipt, board_box_holder.ipt]
2022-07-17 board box - holder fix
    [bar_holder.ipt]
2022-07-17 board box - holders/connectors
    [bar_holder.ipt, board_box.iam, board_box_bar_holder.iam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]
2022-07-17 board box - ready
    [agh_logo.stl, bar_holder.stl, board_box.iam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]
2022-07-18 board box - cables openings
    [board_box_bottom.ipt, board_box_bottom.stl]
2022-07-19 board box - done to be printed
    [board_box.iam, board_box_bottom.ipt, board_box_bottom.stl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]
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2022-07-31 stand - box on stand partially, correction of the arm parts length
    [adjustable_arm.iam, adjustable_double_connector.iam, bar_285mm.ipt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]
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2022-08-04 App - correct GPIO ids
    [stand_driver.py]
2022-08-04 App - try to get image from camera
2022-08-04 App - fixed problem with image reloading
    [normal_map_scanner.py]
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2022-08-05 App - fixed choosing path in calculation menu
    [normal_map_scanner.py, test.py]
2022-08-07 App - fixes in linux
    [normal_map_scanner.py]
2022-08-08 App - check image fix
    [normal_map_scanner.py]
2022-08-11 App - refreshing fix
    [normal_map_scanner.py]
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2022-10-26 stl - bar holder diameter fix
    [bar_holder.ipt, bar_holder.stl]
